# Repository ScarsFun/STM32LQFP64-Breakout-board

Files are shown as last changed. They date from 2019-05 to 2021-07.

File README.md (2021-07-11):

# STM32 LQFP64 BREAKOUT BOARD

This is a 64pin STM32 BREAKOUT BOARD inspired by "blue pill" STM32 48pin board (Maple mini clone).
Same features are Improved:

* 3.3v Power supply and VDDA improvements. 
* USB ESD protection.
* added USB reset circuit (not needed for some MCUs).
* Many Cortex M0, M3, M4 STM32 Microcontrolles may be mounted in this PCB layout.
Check notes in schematic and read STM32 datasheets. 
* Eagle PCB, Schematics.

* RTC oscillator is not implemented because no enought PCB spaces to follow STM design guide. ...I'll be pleased if anyone will find a solution 

# CHANGELOG
## 1.3.1 (2021-07-11)
### Fix:
- Fixed reset circuit.
- Silkscreen improvements.

## 1.3 (2020-06-16)
### Features:
- Added support for STM32F401, STM32F410, STM32F411, STM32F412, STM32F413, STM32F423, STM32F446
### Fix:
- Added partitor to VBUS  

## 1.2 (2018-10-11)
### Fix:
- RTC oscillator design dont works. removed from project 

## 1.1 (2018-07-23)
### Features:
- First release lot of bugs

This work is licensed under a [Creative Commons Attribution 4.0 International License.](http://creativecommons.org/licenses/by/4.0/)

CC

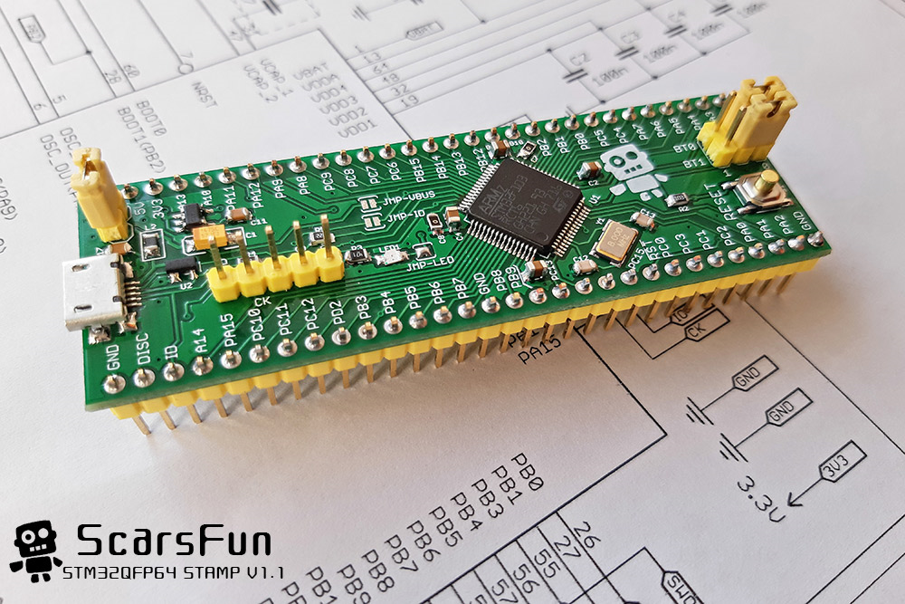
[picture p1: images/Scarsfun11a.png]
PCB_front
 
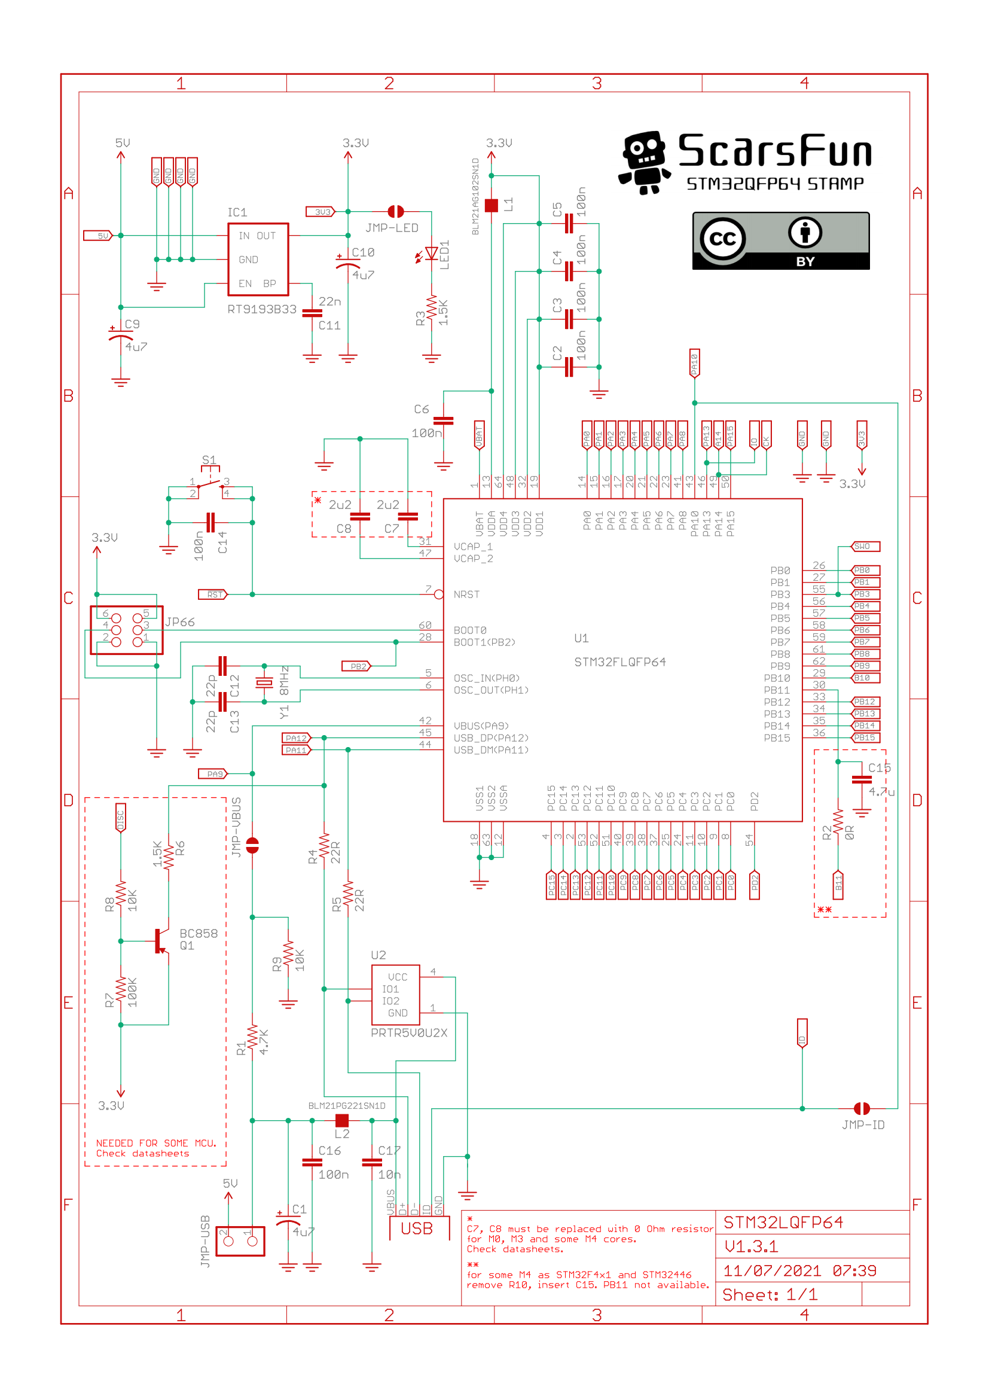
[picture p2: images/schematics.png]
PCB_sch


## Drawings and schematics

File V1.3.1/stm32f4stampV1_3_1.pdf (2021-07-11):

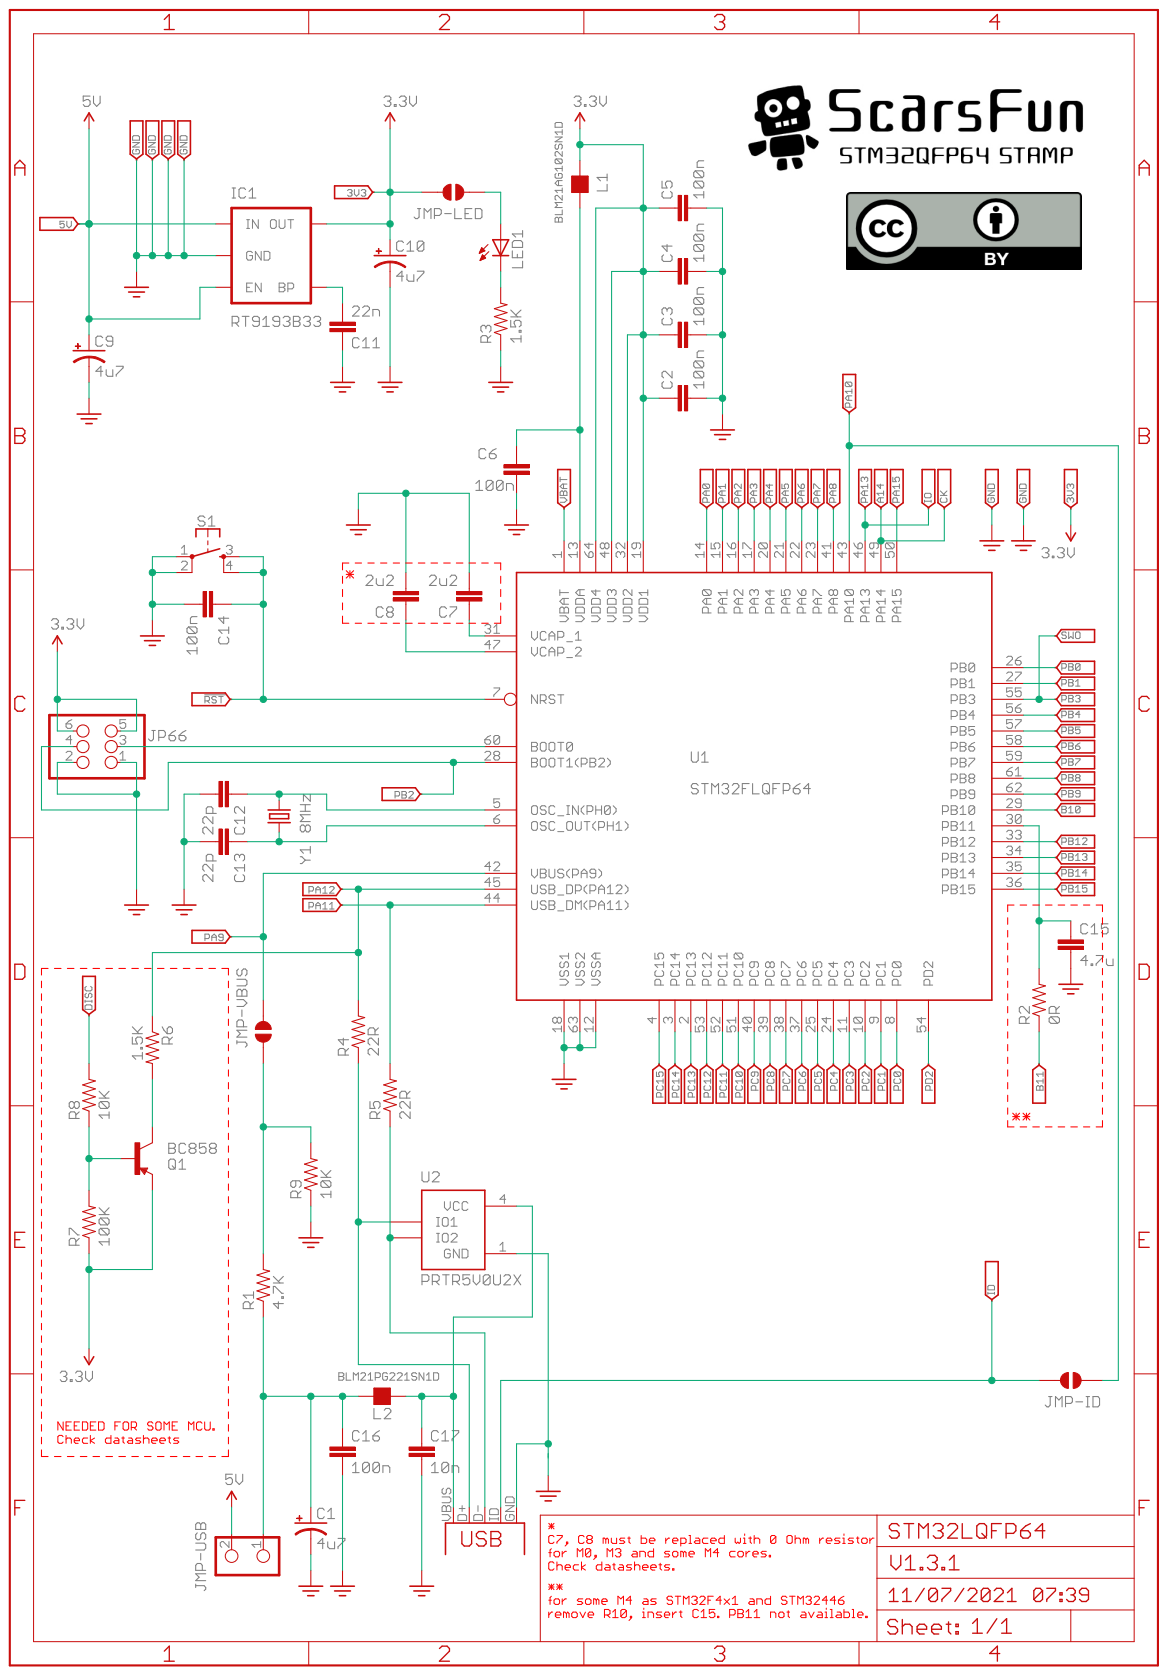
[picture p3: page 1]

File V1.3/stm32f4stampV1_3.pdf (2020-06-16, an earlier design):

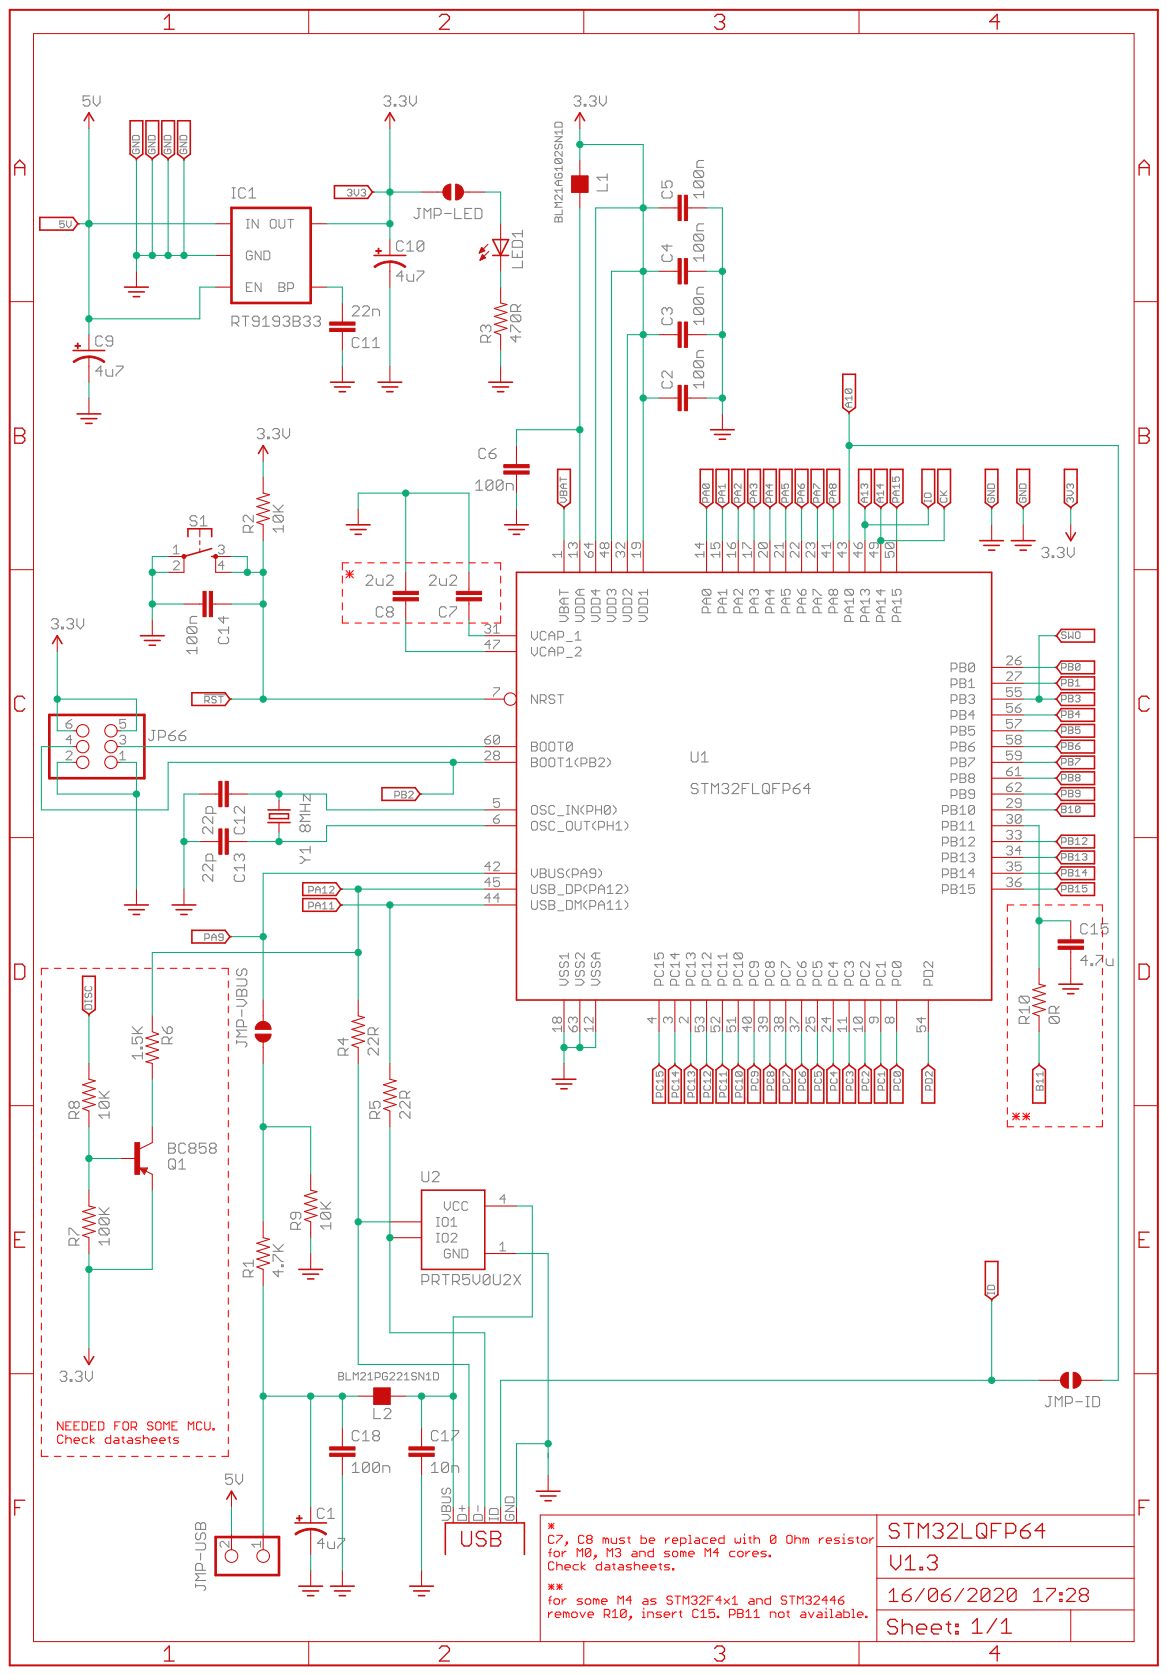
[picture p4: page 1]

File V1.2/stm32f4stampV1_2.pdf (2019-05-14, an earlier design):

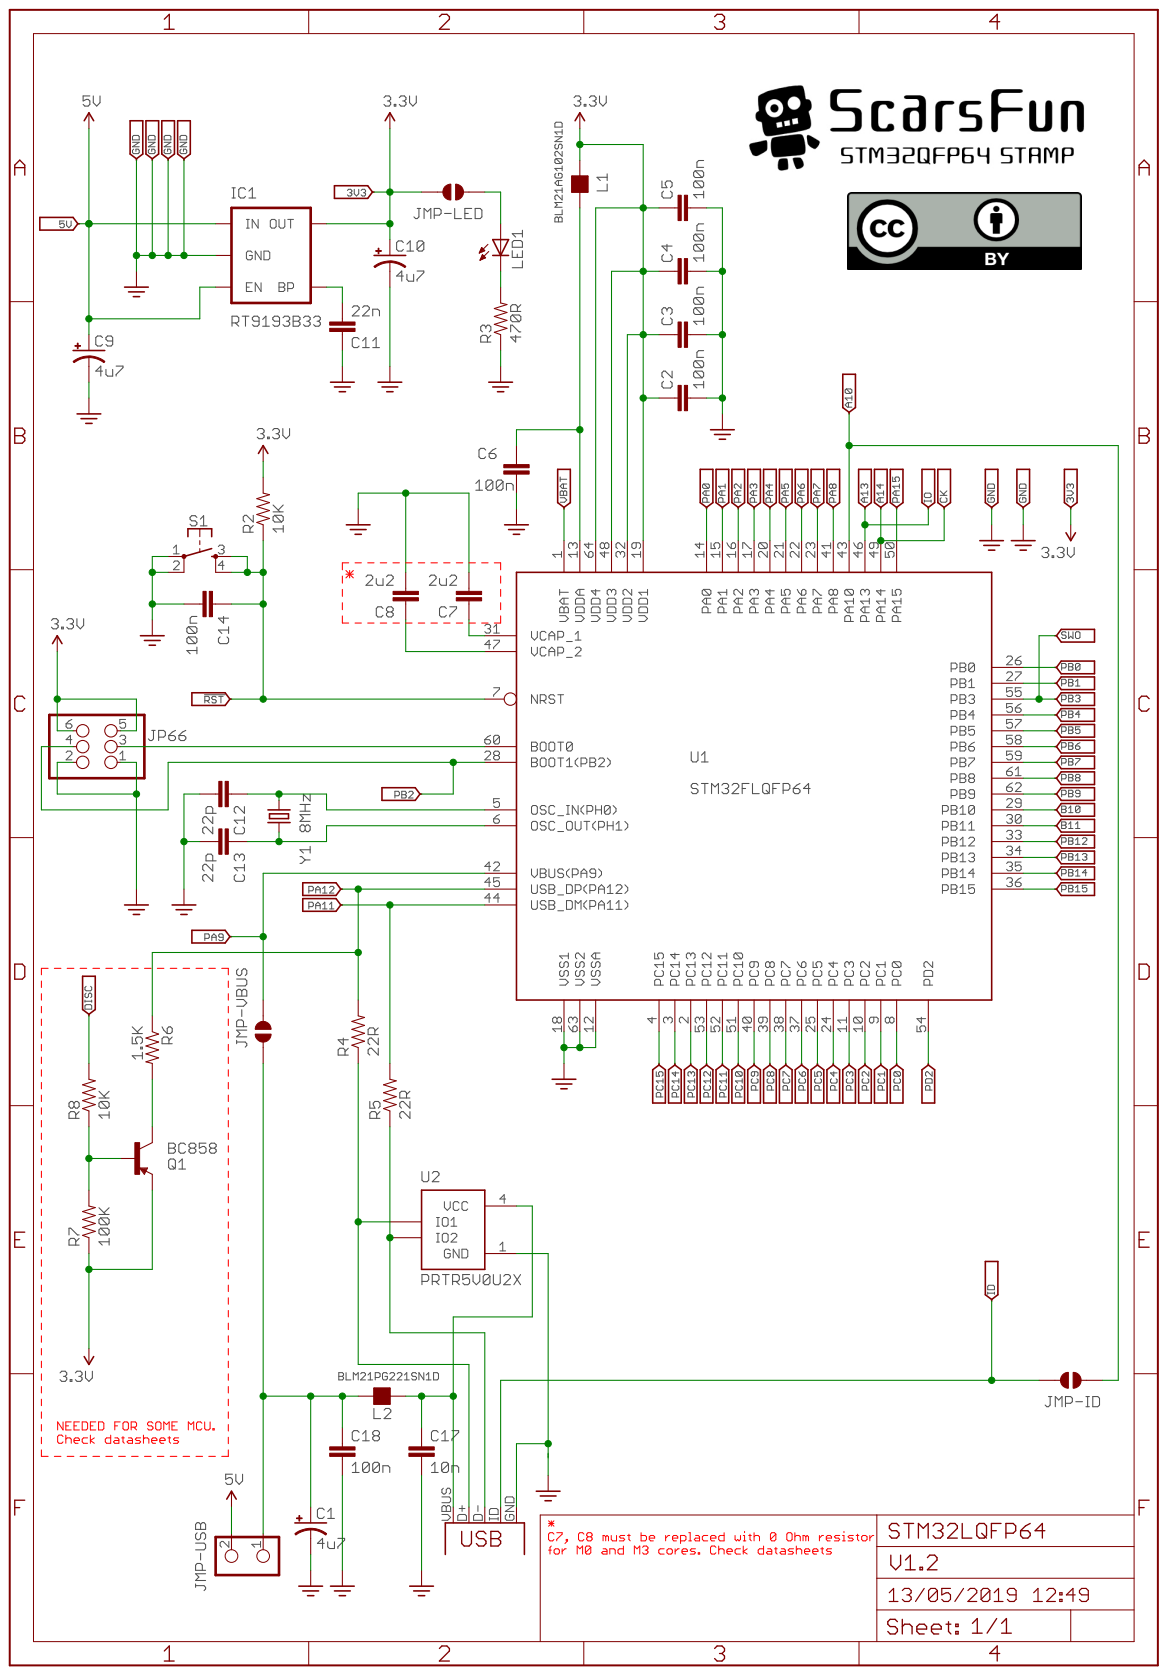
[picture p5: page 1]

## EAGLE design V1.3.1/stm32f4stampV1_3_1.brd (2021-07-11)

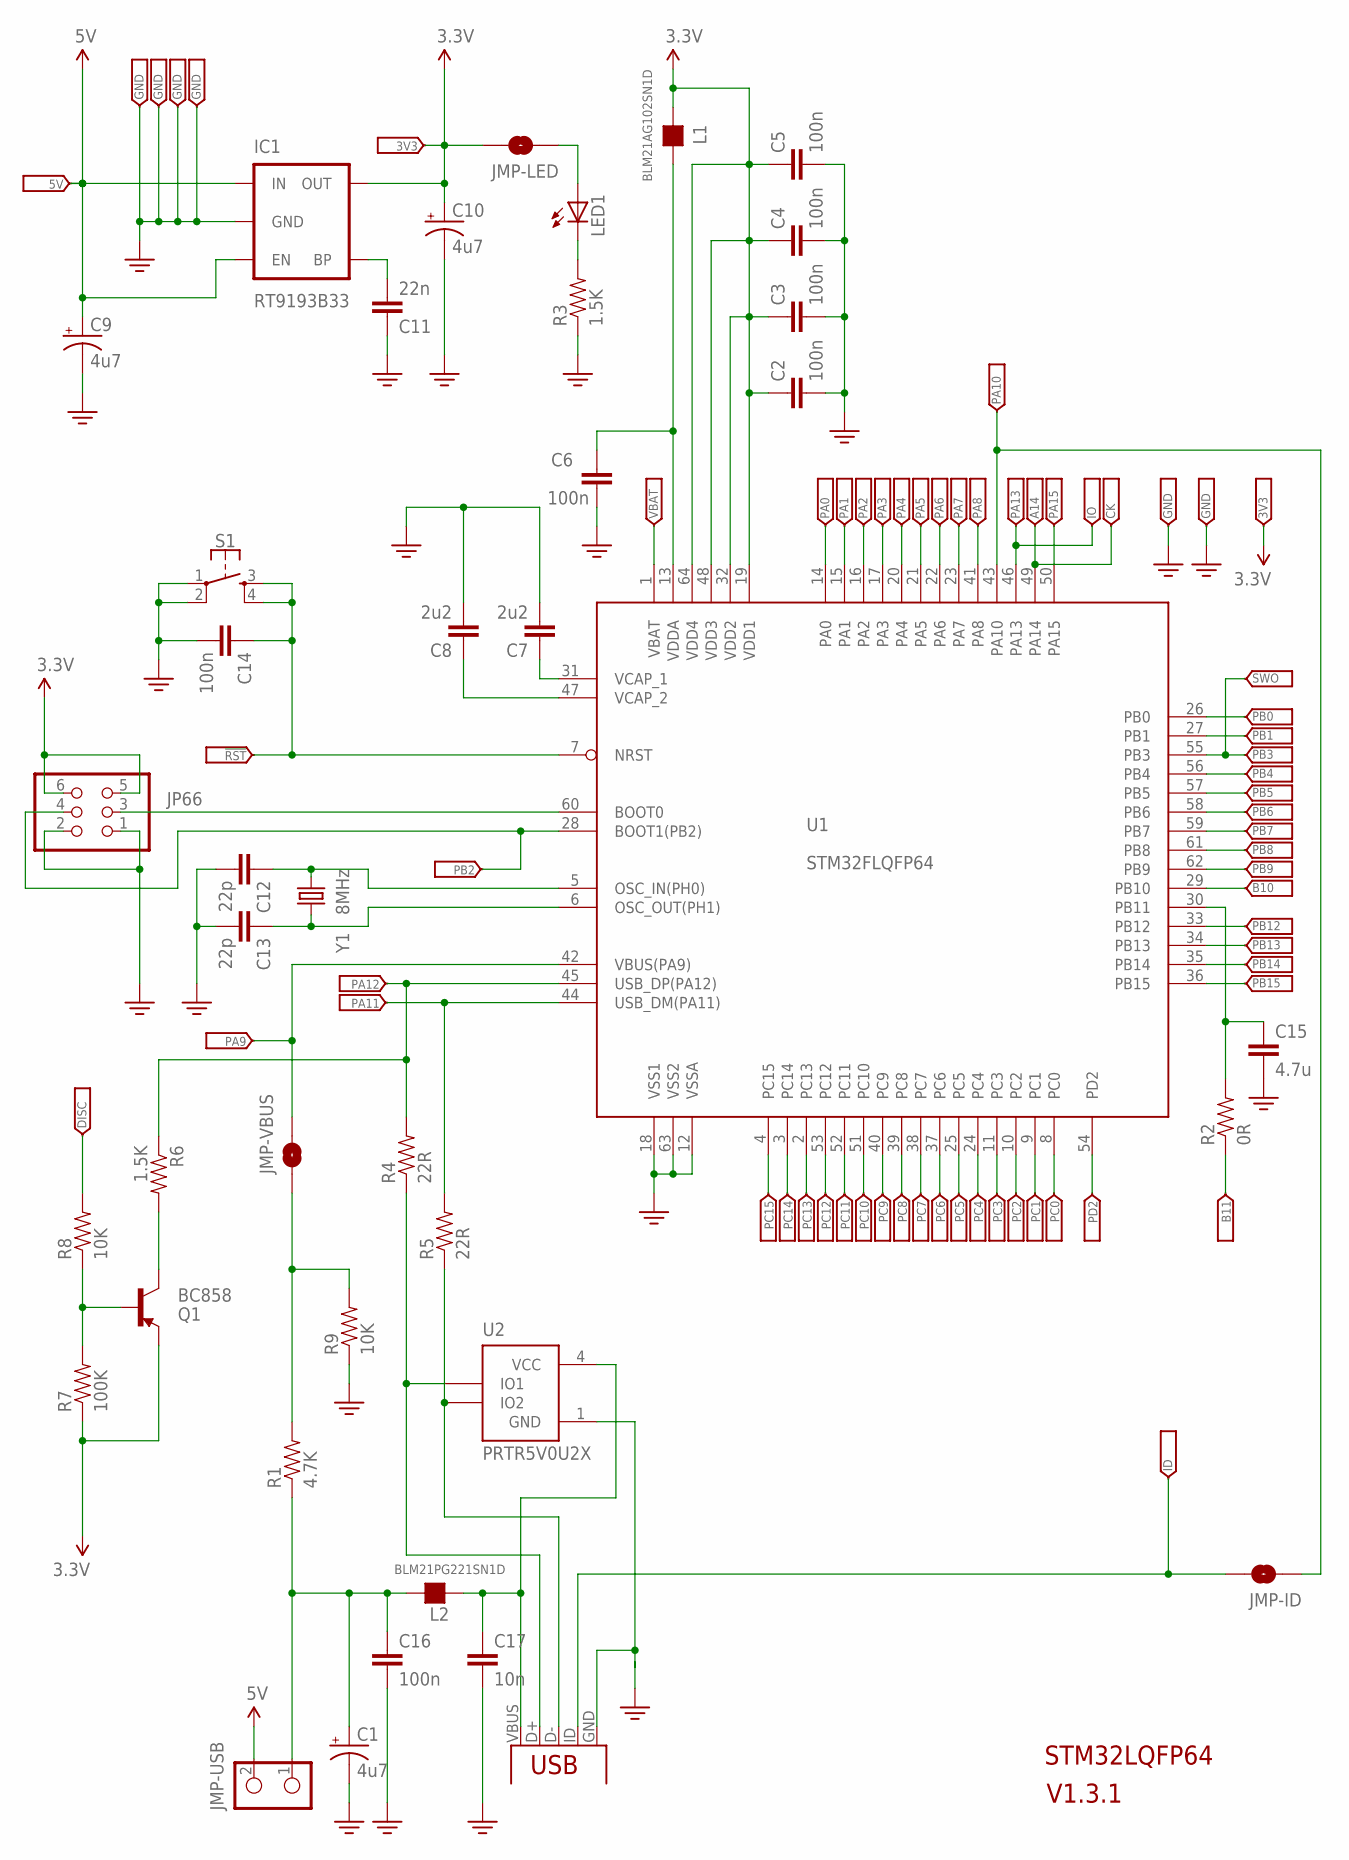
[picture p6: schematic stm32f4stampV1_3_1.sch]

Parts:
C1, C9, C10: 4u7; EIA3216-KIT
C2, C3, C4, C5, C6, C14, C16: 100n; 0805
C7, C8: 2u2; 0805
C11: 22n; 0805
C12, C13: 22p; 0805
C15: 4.7u; 0805
C17: 10n; 0805
IC1: RT9193B33; SOT23-5
JMP-ID: SOLDERJUMPERNO; SJ_2S-NO
JMP-LED: SOLDERJUMPERNO; SJ_2S-NO
JMP-USB: JUMPER-2PTH; 1X02
JMP-VBUS: SOLDERJUMPERNO; SJ_2S-NO
JP1: PA12; 1X1-HEADER-HOLE
JP2: 5V; 1X1-HEADER-HOLE
JP3, JP6, JP7, JP55, JP62, JP65: GND; 1X1-HEADER-HOLE
JP4, JP63: 3V3; 1X1-HEADER-HOLE
JP5: DISC; 1X1-HEADER-HOLE
JP8: PB8; 1X1-HEADER-HOLE
JP9: PA10; 1X1-HEADER-HOLE
JP10: PA8; 1X1-HEADER-HOLE
JP11: PA13; 1X1-HEADER-HOLE
JP12: PC9; 1X1-HEADER-HOLE
JP13: PC15; 1X1-HEADER-HOLE
JP14: PC14; 1X1-HEADER-HOLE
JP15: PC13; 1X1-HEADER-HOLE
JP16: PC12; 1X1-HEADER-HOLE
JP17: PC11; 1X1-HEADER-HOLE
JP18: PC10; 1X1-HEADER-HOLE
JP19: PC8; 1X1-HEADER-HOLE
JP20: PC7; 1X1-HEADER-HOLE
JP21: PC6; 1X1-HEADER-HOLE
JP22: PC5; 1X1-HEADER-HOLE
JP23: PC4; 1X1-HEADER-HOLE
JP24: PC3; 1X1-HEADER-HOLE
JP25: PC2; 1X1-HEADER-HOLE
JP26: PC1; 1X1-HEADER-HOLE
JP27: PC0; 1X1-HEADER-HOLE
JP28: PD2; 1X1-HEADER-HOLE
JP29: PA0; 1X1-HEADER-HOLE
JP30: PA1; 1X1-HEADER-HOLE
JP31: PA2; 1X1-HEADER-HOLE
JP32: PA3; 1X1-HEADER-HOLE
JP33: PA4; 1X1-HEADER-HOLE
JP34: PA5; 1X1-HEADER-HOLE
JP35: PA6; 1X1-HEADER-HOLE
JP36: PA7; 1X1-HEADER-HOLE
JP37: A14; 1X1-HEADER-HOLE
JP38: PA15; 1X1-HEADER-HOLE
JP39: PB0; 1X1-HEADER-HOLE
JP40: PB1; 1X1-HEADER-HOLE
JP41: PB3; 1X1-HEADER-HOLE
JP42: PB4; 1X1-HEADER-HOLE
JP43: PB5; 1X1-HEADER-HOLE
JP44: PB6; 1X1-HEADER-HOLE
JP45: PB7; 1X1-HEADER-HOLE
JP46: PB9; 1X1-HEADER-HOLE
JP47: B10; 1X1-HEADER-HOLE
JP48: B11; 1X1-HEADER-HOLE
JP49: PB12; 1X1-HEADER-HOLE
JP50: PB13; 1X1-HEADER-HOLE
JP51: PB14; 1X1-HEADER-HOLE
JP52: PB15; 1X1-HEADER-HOLE
JP53: VBAT; 1X1-HEADER-HOLE
JP54: !RST; 1X1-HEADER-HOLE
JP56: ID; 1X1-HEADER-HOLE
JP57: PB2; 1X1-HEADER-HOLE
JP58: PA11; 1X1-HEADER-HOLE
JP59: IO; 1X1-HEADER-HOLE
JP60: CK; 1X1-HEADER-HOLE
JP61: SWO; 1X1-HEADER-HOLE
JP64: PA9; 1X1-HEADER-HOLE
JP66: PINHD-2X3; 2X03
L1: BLM21AG102SN1D; L0805
L2: BLM21PG221SN1D; L0805
LED1: LEDSML0805; SML0805
Q1: BC858; SOT23-3
R1: 4.7K; 0805
R2: 0R; 0805
R3, R6: 1.5K; 0805
R4, R5: 22R; 0805
R7: 100K; 0805
R8, R9: 10K; 0805
S1: MOMENTARY-SWITCH-SPST-2-SMD-5.2MM; TACTILE_SWITCH_SMD_5.2MM
U1: STM32FLQFP64; LQFP64
U2: PRTR5V0U2X; SOT-143B
USB: USB-MICROB-SMD
Y1: 8MHz; CRYSTAL-SMD-5X3

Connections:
3.3V: C2.1, C3.1, C4.1, C5.1, C10.A (+), IC1.5 (OUT), JMP-LED.2, JP4.1, JP63.1, JP66.5, JP66.6, L1.2, Q1.2 (E), R7.1, U1.19 (VDD1), U1.32 (VDD2), U1.48 (VDD3), U1.64 (VDD4)
5V: C9.A (+), IC1.1 (IN), IC1.3 (EN), JMP-USB.2, JP2.1
GND: C1.C (-), C2.2, C3.2, C4.2, C5.2, C6.2, C7.2, C8.2, C9.C (-), C10.C (-), C11.1, C12.2, C13.2, C14.2, C15.2, C16.2, C17.2, IC1.2 (GND), JP3.1, JP6.1, JP7.1, JP55.1, JP62.1, JP65.1, JP66.1, JP66.2, R3.1, R9.1, S1.1, S1.2, U1.12 (VSSA), U1.18 (VSS1), U1.63 (VSS2), U2.1 (GND), USB.GND, USB.MT1, USB.MT2, USB.MT3, USB.MT4
unnamed: JP1.1, R4.2, R6.1, U1.45 (USB_DP(PA12))
unnamed: JP13.1, U1.4 (PC15)
unnamed: C1.A (+), C16.1, JMP-USB.1, L2.2, R1.1
unnamed: JP12.1, U1.40 (PC9)
unnamed: C17.1, L2.1, U2.4 (VCC), USB.VBUS
unnamed: JP58.1, R5.2, U1.44 (USB_DM(PA11))
unnamed: JP8.1, U1.61 (PB8)
unnamed: C11.2, IC1.4 (BP)
unnamed: JP66.3, U1.60 (BOOT0)
unnamed: JP10.1, U1.41 (PA8)
unnamed: JP11.1, JP59.1, U1.46 (PA13)
unnamed: C13.1, U1.6 (OSC_OUT(PH1)), Y1.1
unnamed: C7.1, U1.31 (VCAP_1)
unnamed: C8.1, U1.47 (VCAP_2)
unnamed: C12.1, U1.5 (OSC_IN(PH0)), Y1.3 (2)
unnamed: JP57.1, JP66.4, U1.28 (BOOT1(PB2))
unnamed: C14.1, JP54.1, S1.3, S1.4, U1.7 (NRST)
unnamed: LED1.C, R3.2
unnamed: C6.1, L1.1, U1.13 (VDDA)
unnamed: JMP-ID.2, JP56.1, USB.ID
unnamed: R5.1, U2.3 (IO2), USB.D-
unnamed: JMP-ID.1, JP9.1, U1.43 (PA10)
unnamed: JP14.1, U1.3 (PC14)
unnamed: JMP-VBUS.1, R1.2, R9.2
unnamed: JP15.1, U1.2 (PC13)
unnamed: JP16.1, U1.53 (PC12)
unnamed: JP17.1, U1.52 (PC11)
unnamed: JP18.1, U1.51 (PC10)
unnamed: JP19.1, U1.39 (PC8)
unnamed: JP20.1, U1.38 (PC7)
unnamed: JP21.1, U1.37 (PC6)
unnamed: JP22.1, U1.25 (PC5)
unnamed: JP23.1, U1.24 (PC4)
unnamed: JP24.1, U1.11 (PC3)
unnamed: JP25.1, U1.10 (PC2)
unnamed: JP26.1, U1.9 (PC1)
unnamed: JP27.1, U1.8 (PC0)
unnamed: JP28.1, U1.54 (PD2)
unnamed: JP29.1, U1.14 (PA0)
unnamed: JP30.1, U1.15 (PA1)
unnamed: JP31.1, U1.16 (PA2)
unnamed: JP32.1, U1.17 (PA3)
unnamed: JP33.1, U1.20 (PA4)
unnamed: JP34.1, U1.21 (PA5)
unnamed: JP35.1, U1.22 (PA6)
unnamed: JP36.1, U1.23 (PA7)
unnamed: JP37.1, JP60.1, U1.49 (PA14)
unnamed: JP38.1, U1.50 (PA15)
unnamed: JP39.1, U1.26 (PB0)
unnamed: JP40.1, U1.27 (PB1)
unnamed: JP41.1, JP61.1, U1.55 (PB3)
unnamed: JP42.1, U1.56 (PB4)
unnamed: JP43.1, U1.57 (PB5)
unnamed: JP44.1, U1.58 (PB6)
unnamed: JP45.1, U1.59 (PB7)
unnamed: JP46.1, U1.62 (PB9)
unnamed: JP47.1, U1.29 (PB10)
unnamed: C15.1, R2.2, U1.30 (PB11)
unnamed: JP49.1, U1.33 (PB12)
unnamed: JP50.1, U1.34 (PB13)
unnamed: JP51.1, U1.35 (PB14)
unnamed: JP52.1, U1.36 (PB15)
unnamed: JP53.1, U1.1 (VBAT)
unnamed: R4.1, U2.2 (IO1), USB.D+
unnamed: JMP-LED.1, LED1.A
unnamed: JMP-VBUS.2, JP64.1, U1.42 (VBUS(PA9))
unnamed: Q1.3 (C), R6.2
unnamed: JP48.1, R2.1
unnamed: Q1.1 (B), R7.2, R8.1
unnamed: JP5.1, R8.2

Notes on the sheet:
STM32LQFP64
V1.3.1

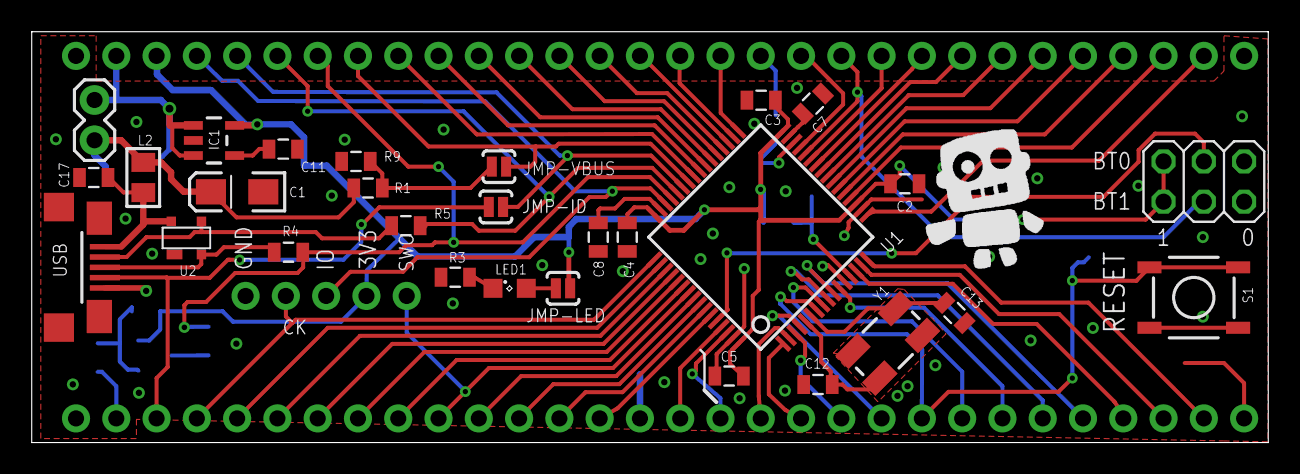
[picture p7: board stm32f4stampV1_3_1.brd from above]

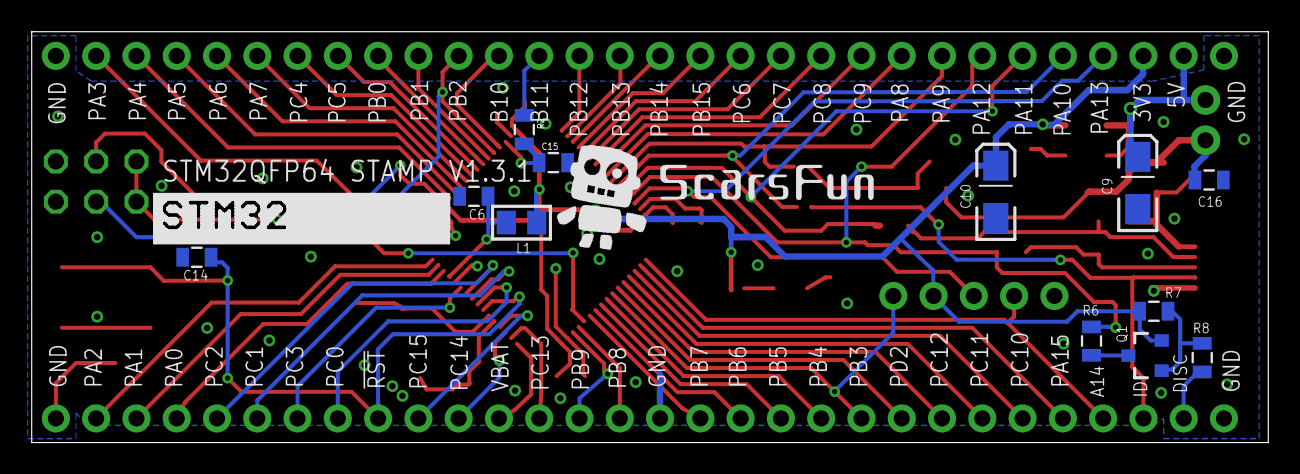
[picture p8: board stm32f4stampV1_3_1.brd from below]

Board: 2 copper layers, 78.0 x 25.9 mm, 106 parts (12 on the bottom side), 73 nets.

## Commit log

2020-06-16 V1.3 released
    [stm32f4stampV1_3.brd, stm32f4stampV1_3.sch]
2021-07-11 V1.3.1 update
    [stm32f4stampV1_3_1.brd, stm32f4stampV1_3_1.sch]

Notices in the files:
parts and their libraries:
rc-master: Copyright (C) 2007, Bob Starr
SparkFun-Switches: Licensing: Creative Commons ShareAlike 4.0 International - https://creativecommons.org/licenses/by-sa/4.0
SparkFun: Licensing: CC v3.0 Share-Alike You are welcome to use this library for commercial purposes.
